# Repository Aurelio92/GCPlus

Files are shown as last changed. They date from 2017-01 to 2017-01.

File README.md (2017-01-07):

# GC+ - What is it?
GC+ is a custom board that acts as a Gamecube controller with an upgradable firmware and custom features.
Video reference: https://www.youtube.com/watch?v=MTG2iqWmXx4

# How to make one?
You can order the PCBs from OshPark: https://oshpark.com/shared_projects/pEYojr6X

# Needed parts
A BOM is available in the Hardware folder

# How to flash it
Flash GC+.hex with MPLAB IPE (http://microchip.wikidot.com/ipe:installation) and a PICKIT v3.

# License

MIT License

Copyright (c) 2016 Aurelio Mannara

Permission is hereby granted, free of charge, to any person obtaining a copy
of this software and associated documentation files (the "Software"), to deal
in the Software without restriction, including without limitation the rights
to use, copy, modify, merge, publish, distribute, sublicense, and/or sell
copies of the Software, and to permit persons to whom the Software is
furnished to do so, subject to the following conditions:

The above copyright notice and this permission notice shall be included in all
copies or substantial portions of the Software.

THE SOFTWARE IS PROVIDED "AS IS", WITHOUT WARRANTY OF ANY KIND, EXPRESS OR
IMPLIED, INCLUDING BUT NOT LIMITED TO THE WARRANTIES OF MERCHANTABILITY,
FITNESS FOR A PARTICULAR PURPOSE AND NONINFRINGEMENT. IN NO EVENT SHALL THE
AUTHORS OR COPYRIGHT HOLDERS BE LIABLE FOR ANY CLAIM, DAMAGES OR OTHER
LIABILITY, WHETHER IN AN ACTION OF CONTRACT, TORT OR OTHERWISE, ARISING FROM,
OUT OF OR IN CONNECTION WITH THE SOFTWARE OR THE USE OR OTHER DEALINGS IN THE
SOFTWARE.

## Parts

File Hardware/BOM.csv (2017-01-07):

Part | Value | Package
C1 | 100 nF | 0805
C2 | 100 nF | 0805
D1 | 1N4148 | SOD-323
IC1 | PIC18F25K22-I/SS | SSOP28
R1 | 10 kohm | 0805
R2 | 10 kohm | 0805
R3 | 10 kohm | 0805
R4 | 10 kohm | 0805
R5 | 10 kohm | 0805
R6 | 10 kohm | 0805
R7 | 10 kohm | 0805
R8 | 10 kohm | 0805
R9 | 10 kohm | 0805
R10 | 100 ohm | 0805
R11 | 10 kohm | 0805
R12 | 10 kohm | 0805
R13 | 10 kohm | 0805
R14 | 10 kohm | 0805
R15 | 10 kohm | 0805
R16 | 10 kohm | 0805
T1 | BSS138_F085 | SOT-23-3

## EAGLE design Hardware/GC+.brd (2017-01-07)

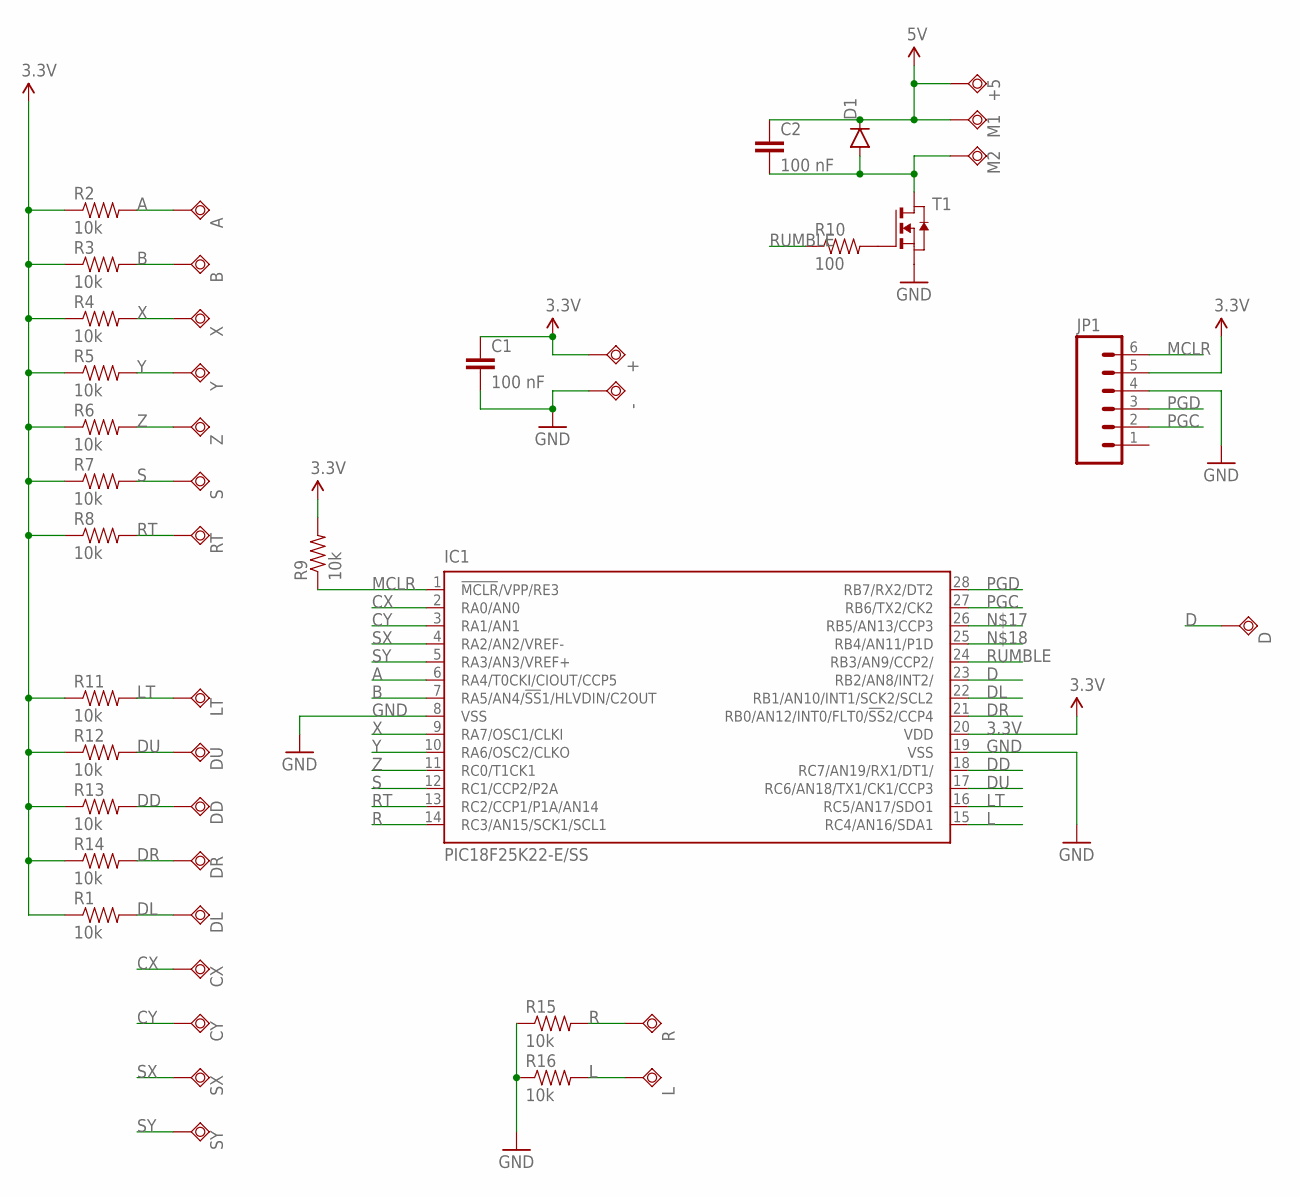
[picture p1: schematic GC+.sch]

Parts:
+, +5: TPSQTP10SQ; TP10SQ
-: TPSQTP10SQ; TP10SQ
A: TPSQTP10SQ; TP10SQ
B: TPSQTP10SQ; TP10SQ
C1, C2: 100 nF; 0805
CX: TPSQTP10SQ; TP10SQ
CY: TPSQTP10SQ; TP10SQ
D: TPSQTP10SQ; TP10SQ
D1: DIODEBAS16; SOD-323
DD: TPSQTP10SQ; TP10SQ
DL: TPSQTP10SQ; TP10SQ
DR: TPSQTP10SQ; TP10SQ
DU: TPSQTP10SQ; TP10SQ
IC1: PIC18F25K22-E/SS; SSOP28
JP1: M06SILK_FEMALE_PTH; 1X06
L: TPSQTP10SQ; TP10SQ
LT: TPSQTP10SQ; TP10SQ
M1, M2: TPSQTP10SQ; TP10SQ
R: TPSQTP10SQ; TP10SQ
R1, R2, R3, R4, R5, R6, R7, R8, R9, R11, R12, R13, R14, R15, R16: 10k; 0805
R10: 100; 0805
RT: TPSQTP10SQ; TP10SQ
S: TPSQTP10SQ; TP10SQ
SX: TPSQTP10SQ; TP10SQ
SY: TPSQTP10SQ; TP10SQ
T1: NMOSSOT23; SOT-23
X: TPSQTP10SQ; TP10SQ
Y: TPSQTP10SQ; TP10SQ
Z: TPSQTP10SQ; TP10SQ

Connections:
3.3V: +.TP, C1.1, IC1.20 (VDD), JP1.5, R1.1, R2.1, R3.1, R4.1, R5.1, R6.1, R7.1, R8.1, R9.2, R11.1, R12.1, R13.1, R14.1
5V: +5.TP, C2.1, D1.C, M1.TP
A: A.TP, IC1.6 (RA4/T0CKI/CIOUT/CCP5), R2.2
B: B.TP, IC1.7 (RA5/AN4/!SS!1/HLVDIN/C2OUT), R3.2
CX: CX.TP, IC1.2 (RA0/AN0)
CY: CY.TP, IC1.3 (RA1/AN1)
D: D.TP, IC1.23 (RB2/AN8/INT2/)
DD: DD.TP, IC1.18 (RC7/AN19/RX1/DT1/), R13.2
DL: DL.TP, IC1.22 (RB1/AN10/INT1/SCK2/SCL2), R1.2
DR: DR.TP, IC1.21 (RB0/AN12/INT0/FLT0/!SS!2/CCP4), R14.2
DU: DU.TP, IC1.17 (RC6/AN18/TX1/CK1/CCP3), R12.2
GND: -.TP, C1.2, IC1.8 (VSS), IC1.19 (VSS), JP1.4, R15.1, R16.1, T1.2 (S)
L: IC1.15 (RC4/AN16/SDA1), L.TP, R16.2
LT: IC1.16 (RC5/AN17/SDO1), LT.TP, R11.2
MCLR: IC1.1 (!MCLR!/VPP/RE3), JP1.6, R9.1
unnamed: R10.2, T1.3 (G)
unnamed: C2.2, D1.A, M2.TP, T1.1 (D)
PGC: IC1.27 (RB6/TX2/CK2), JP1.2
PGD: IC1.28 (RB7/RX2/DT2), JP1.3
R: IC1.14 (RC3/AN15/SCK1/SCL1), R.TP, R15.2
RT: IC1.13 (RC2/CCP1/P1A/AN14), R8.2, RT.TP
RUMBLE: IC1.24 (RB3/AN9/CCP2/), R10.1
S: IC1.12 (RC1/CCP2/P2A), R7.2, S.TP
SX: IC1.4 (RA2/AN2/VREF-), SX.TP
SY: IC1.5 (RA3/AN3/VREF+), SY.TP
X: IC1.9 (RA7/OSC1/CLKI), R4.2, X.TP
Y: IC1.10 (RA6/OSC2/CLKO), R5.2, Y.TP
Z: IC1.11 (RC0/T1CK1), R6.2, Z.TP

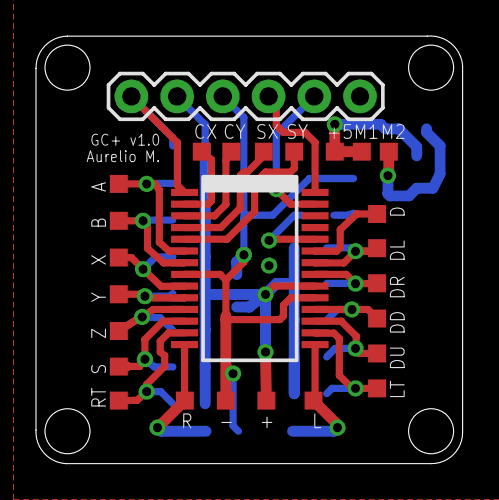
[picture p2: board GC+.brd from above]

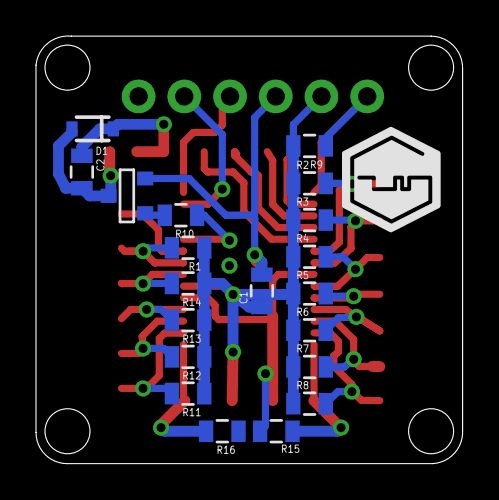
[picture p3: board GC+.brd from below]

Board: 2 copper layers, 23.7 x 23.8 mm, 47 parts (20 on the bottom side), 28 nets.

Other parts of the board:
U$1: LOGOGC

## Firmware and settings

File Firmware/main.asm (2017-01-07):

; GC+ by Aurelio Mannara


; MIT License
; 
; Copyright (c) 2016 Aurelio Mannara
; 
; Permission is hereby granted, free of charge, to any person obtaining a copy
; of this software and associated documentation files (the "Software"), to deal
; in the Software without restriction, including without limitation the rights
; to use, copy, modify, merge, publish, distribute, sublicense, and/or sell
; copies of the Software, and to permit persons to whom the Software is
; furnished to do so, subject to the following conditions:
; 
; The above copyright notice and this permission notice shall be included in all
; copies or substantial portions of the Software.
; 
; THE SOFTWARE IS PROVIDED "AS IS", WITHOUT WARRANTY OF ANY KIND, EXPRESS OR
; IMPLIED, INCLUDING BUT NOT LIMITED TO THE WARRANTIES OF MERCHANTABILITY,
; FITNESS FOR A PARTICULAR PURPOSE AND NONINFRINGEMENT. IN NO EVENT SHALL THE
; AUTHORS OR COPYRIGHT HOLDERS BE LIABLE FOR ANY CLAIM, DAMAGES OR OTHER
; LIABILITY, WHETHER IN AN ACTION OF CONTRACT, TORT OR OTHERWISE, ARISING FROM,
; OUT OF OR IN CONNECTION WITH THE SOFTWARE OR THE USE OR OTHER DEALINGS IN THE
; SOFTWARE.

#include "p18F25K22.inc"

; CONFIG1H
  CONFIG  FOSC = INTIO67        ; Oscillator Selection bits (Internal oscillator block)
  CONFIG  PLLCFG = ON           ; 4X PLL Enable (Oscillator multiplied by 4)
  CONFIG  PRICLKEN = OFF        ; Primary clock enable bit (Primary clock can be disabled by software)
  CONFIG  FCMEN = OFF           ; Fail-Safe Clock Monitor Enable bit (Fail-Safe Clock Monitor disabled)
  CONFIG  IESO = OFF            ; Internal/External Oscillator Switchover bit (Oscillator Switchover mode disabled)

; CONFIG2L
  CONFIG  PWRTEN = OFF          ; Power-up Timer Enable bit (Power up timer disabled)
  CONFIG  BOREN = SBORDIS       ; Brown-out Reset Enable bits (Brown-out Reset enabled in hardware only (SBOREN is disabled))
  CONFIG  BORV = 190            ; Brown Out Reset Voltage bits (VBOR set to 1.90 V nominal)

; CONFIG2H
  CONFIG  WDTEN = SWON          ; Watchdog Timer Enable bits (WDT is controlled by SWDTEN bit of the WDTCON register)
  CONFIG  WDTPS = 1024          ; Watchdog Timer Postscale Select bits (1:1024)

; CONFIG3H
  CONFIG  CCP2MX = PORTB3       ; CCP2 MUX bit (CCP2 input/output is multiplexed with RB3)
  CONFIG  PBADEN = ON           ; PORTB A/D Enable bit (PORTB<5:0> pins are configured as analog input channels on Reset)
  CONFIG  CCP3MX = PORTB5       ; P3A/CCP3 Mux bit (P3A/CCP3 input/output is multiplexed with RB5)
  CONFIG  HFOFST = ON           ; HFINTOSC Fast Start-up (HFINTOSC output and ready status are not delayed by the oscillator stable status)
  CONFIG  T3CMX = PORTC0        ; Timer3 Clock input mux bit (T3CKI is on RC0)
  CONFIG  P2BMX = PORTB5        ; ECCP2 B output mux bit (P2B is on RB5)
  CONFIG  MCLRE = EXTMCLR       ; MCLR Pin Enable bit (MCLR pin enabled, RE3 input pin disabled)

; CONFIG4L
  CONFIG  STVREN = ON           ; Stack Full/Underflow Reset Enable bit (Stack full/underflow will cause Reset)
  CONFIG  LVP = ON              ; Single-Supply ICSP Enable bit (Single-Supply ICSP enabled if MCLRE is also 1)
  CONFIG  XINST = OFF           ; Extended Instruction Set Enable bit (Instruction set extension and Indexed Addressing mode disabled (Legacy mode))

; CONFIG5L
  CONFIG  CP0 = ON             ; Code Protection Block 0 (Block 0 (000800-001FFFh) code-protected)
  CONFIG  CP1 = ON             ; Code Protection Block 1 (Block 1 (002000-003FFFh) code-protected)
  CONFIG  CP2 = ON             ; Code Protection Block 2 (Block 2 (004000-005FFFh) code-protected)
  CONFIG  CP3 = ON             ; Code Protection Block 3 (Block 3 (006000-007FFFh) code-protected)

; CONFIG5H
  CONFIG  CPB = ON             ; Boot Block Code Protection bit (Boot block (000000-0007FFh) code-protected)
  CONFIG  CPD = OFF            ; Data EEPROM Code Protection bit (Data EEPROM not code-protected)

; CONFIG6L
  CONFIG  WRT0 = ON             ; Write Protection Block 0 (Block 0 (000800-001FFFh) write-protected)
  CONFIG  WRT1 = OFF            ; Write Protection Block 1 (Block 1 (002000-003FFFh) not write-protected)
  CONFIG  WRT2 = OFF            ; Write Protection Block 2 (Block 2 (004000-005FFFh) not write-protected)
  CONFIG  WRT3 = OFF            ; Write Protection Block 3 (Block 3 (006000-007FFFh) not write-protected)

; CONFIG6H
  CONFIG  WRTC = ON             ; Configuration Register Write Protection bit (Configuration registers (300000-3000FFh) write-protected)
  CONFIG  WRTB = ON             ; Boot Block Write Protection bit (Boot Block (000000-0007FFh) write-protected)
  CONFIG  WRTD = OFF            ; Data EEPROM Write Protection bit (Data EEPROM not write-protected)

; CONFIG7L
  CONFIG  EBTR0 = ON            ; Table Read Protection Block 0 (Block 0 (000800-001FFFh) protected from table reads executed in other blocks)
  CONFIG  EBTR1 = ON            ; Table Read Protection Block 1 (Block 1 (002000-003FFFh) protected from table reads executed in other blocks)
  CONFIG  EBTR2 = ON            ; Table Read Protection Block 2 (Block 2 (004000-005FFFh) protected from table reads executed in other blocks)
  CONFIG  EBTR3 = ON            ; Table Read Protection Block 3 (Block 3 (006000-007FFFh) protected from table reads executed in other blocks)

; CONFIG7H
  CONFIG  EBTRB = ON            ; Boot Block Table Read Protection bit (Boot Block (000000-0007FFh) protected from table reads executed in other blocks)

;Some global variables
bitCounter equ 0x00
tempCmdByte equ 0x01
cmdReceived equ 0x02
cmdLength equ 0x03
charToSendUart1 equ 0x04
dataLength equ 0x05
bitCounterTX equ 0x06
curByte equ 0x07
waitLoopCounter equ 0x08
curADInput equ 0x09
f_divhi equ 0x0A
f_divlo equ 0x0B
lutCounter equ 0x0C
invertAxes equ 0x0D
deadZoneSize equ 0x0E
rumbleDutyCycle equ 0x0F
 
;0x10-0x1F received commands
;0x20-0x22 0x00 answer
;0x23-0x24 buttons current state
buttonsCurState0 equ 0x23
buttonsCurState1 equ 0x24
;0x25-0x26 buttons prev state
buttonsPrevState0 equ 0x25
buttonsPrevState1 equ 0x26
;0x27-0x2C buttons timers
buttonsTimerA equ 0x27
buttonsTimerB equ 0x28
buttonsTimerX equ 0x29
buttonsTimerY equ 0x2A
buttonsTimerZ equ 0x2B
buttonsTimerS equ 0x2C
;0x2D-0x2E mixed buttons state
buttonsMixState0 equ 0x2D
buttonsMixState1 equ 0x2E
;0x30-0x37 0x40 answer
;0x38-0x3D buttons timers
buttonsTimerRT equ 0x38
buttonsTimerLT equ 0x39
buttonsTimerDU equ 0x3A
buttonsTimerDD equ 0x3B
buttonsTimerDR equ 0x3C
buttonsTimerDL equ 0x3D
;0x3E flagsSettings
flagsSettings equ 0x3E
;0x3F analog mode
analogMode equ 0x3F
;0x40-0x4F 0x41-0x42 answer
;0x50-0x55 AD inputs
;0x56-0x5B AD origins

;0x100-0x1FF SX LUT
;0x200-0x2FF SY LUT
;0x300-0x3FF CX LUT
;0x400-0x4FF CY LUT

;Global constant values
firmMajVer equ 1
firmMinVer equ 1
boardMajVer equ 1
boardMinVer equ 0
 
    ;EEPROM default values
    org 0xF00000
    de 0xFF, 0x00, 0xFF, 0x00, 0xFF, 0x00, 0xFF, 0x00, 0x00, 0x18, 0x00


    org 0x00
    goto start
    
    org 0x08 ;High-priority interrupts
    goto isrHighHandler
    
    org 0x18 ;Low-priority interrupts
    goto isrLowHandler

    org 0x20
isrHighHandler
    btfss INTCON3, 1 ;If INT2 flag isn't set just return
    retfie 1 ;Return from interrupt and restore W, STATUS and BSR registers
    ;If we got here, then INT2 flag is set
    
    movlw 0x80 ;Starts from 128 => Wait only 8us
    movwf TMR0L
    bcf INTCON, 2 ;Clear TMR0 flag
    
    ;Check cmdLength
    movf cmdLength, 0, 0 ;WREG = cmdLength
    addlw 0xF1 ;241 = 255 - 14
    addlw 0x0F ;(14 - 0) + 1
    bnc endIsrHighHandler

    ;movlw 0x0E
    ;subfwb cmdLength, 1, 0 ;W = 14 - cmdLength
    ;btfss STATUS, 0 ;Test if cmdLength > 14
    ;bra endIsrHighHandler
    
    ;Wait few cycles => Wait for ~1.25us since the falling edge
    nop
    nop
    nop
    nop
    nop
    nop
    nop
    nop
    nop
    
    ;Check if bitCounter is 8
    movf bitCounter, 0, 0 ;Move bitCounter to W. Use Access Bank
    sublw 8 ;WREG = WREG - 8
    bnz readIsrBit
    
    ;If we got here then we have received a byte
    clrf bitCounter, 0 ;Use Access Bank
    movff tempCmdByte, POSTINC0
    clrf tempCmdByte, 0 ;Use Access Bank
    incf cmdLength, 1, 0 ;Use Access Bank
    
readIsrBit
    
    ;Read the data from RB2 and store it in the tempCmdByte
    rlncf tempCmdByte, 1, 0 ;Use Access Bank
    btfsc PORTB, 2 ;Test RB2. Skip if clear
    bsf tempCmdByte, 0, 0 ;Set the LSB of tempCmdByte if RB2 is set
    incf bitCounter, 1, 0 ;Use Access Bank
    
    
endIsrHighHandler
    bcf INTCON3, 1 ;Clear INT2 flag
    retfie 1 ;Return from interrupt and restore W, STATUS and BSR registers
    
isrLowHandler
    btfsc INTCON, 2 ;Test if the TMR0 overflow occurred
    bra isrTMR0Handler
    
    ;btfsc PIR1, 6 ;Test if AD conversion has happened
    ;bra isrADCHandler
    
    retfie 1 ;Return from interrupt and restore W, STATUS and BSR registers

isrTMR0Handler
    tstfsz cmdLength, 0 ;Skip if cmdLength == 0
    bra isrTMR0CmdReceived
    bra isrTMR0SkipCmdReceived
isrTMR0CmdReceived
    bsf cmdReceived, 0, 0 ;Use Access Bank
    
isrTMR0SkipCmdReceived
    movlw 0x80 ;Starts from 128 => Wait only 8us
    movwf TMR0L
    bcf INTCON, 2 ;Clear TMR0 flag
    retfie 1 ;Return from interrupt and restore W, STATUS and BSR registers
    
    org 0x100
start
    movlb 0xF ; Set BSR for banked SFRs
    bcf INTCON, 7 ;Disable global high interrupts
    bcf WDTCON, 0 ;Make sure that the WDT is disabled
    
    ;Configure oscillator
    movlw 0x74
    movwf OSCCON
    movlw 0x00
    movwf OSCCON2
    movlw 0x40
    movwf OSCTUNE
    ;bsf OSCTUNE, 6 ;OSCTUNE.PLLEN = 1
    
    
    ;Clear the first chunk of memory
    movlw 0x5b
    lfsr FSR0, 0x000
    clrf INDF0
clearMemoryLoop
    movwf FSR0L
    clrf INDF0
    decf WREG
    bnz clearMemoryLoop
    
    
    ;clrf LATB
    ;movlw 0x00
    ;movwf ANSELB
    ;bsf TRISB, 2
    ;bcf LATB, 2
    
    ;Clear global variables to be safe
    clrf tempCmdByte, 0 ;Use Access Bank
    clrf bitCounter, 0 ;Use Access Bank
    clrf cmdReceived, 0 ;Use Access Bank
    clrf cmdLength, 0 ;Use Access Bank
    
    lfsr FSR0, 0x10 ;FSR0 at the beginning of Bank 1
    
    ;CMD 0x00 answer
    lfsr FSR1, 0x20 ;FSR1 at 0x20
    movlw 0x09
    movwf POSTINC1
    movlw 0x00
    movwf POSTINC1
    movlw 0x03
    movwf POSTINC1
    
    ;CMD 0x41-0x42 answer
    lfsr FSR1, 0x40 ;FSR1 at 0x40
    movlw 0x00
    movwf POSTINC1
    movlw 0x80
    movwf POSTINC1
    movlw 0x80
    movwf POSTINC1
    movlw 0x80
    movwf POSTINC1
    movlw 0x80
    movwf POSTINC1
    movlw 0x80
    movwf POSTINC1
    movlw 0x00
    movwf POSTINC1
    movlw 0x00
    movwf POSTINC1
    movlw 0x00
    movwf POSTINC1
    movlw 0x00
    movwf POSTINC1
    
    ;Configuring analog inputs
    movlw 0x0F
    movwf ANSELA
    movlw 0x00
    movwf ANSELB
    movlw 0x18
    movwf ANSELC
    
    ;Setting inputs
    movlw 0xFF
    movwf TRISA
    movlw 0x07
    movwf TRISB
    movlw 0xFF
    movwf TRISC
    
    ;Set ADC
    movlw 0x09
    movwf ADCON0
    movlw 0x00
    movwf ADCON1
    movlw 0x3E
    ;movlw 0x08
    movwf ADCON2
    
    bcf PIR1, 6 ;ADIF = 0
    bcf PIE1, 6 ;ADIE = 0
    bcf IPR1, 6 ;ADIP low priority
    
    call buildOrigins

    ;Check if the board is booted in safe mode
    ;Hold X+Y+Z for safe mode
    bsf flagsSettings, 0, 0 ;Enable safe mode
    btfsc PORTA, 7 ;Skip if X is pressed
    bcf flagsSettings, 0, 0 ;Disable safe mode
    btfsc PORTA, 6 ;Skip if Y is pressed
    bcf flagsSettings, 0, 0 ;Disable safe mode
    btfsc PORTC, 0 ;Skip if Z is pressed
    bcf flagsSettings, 0, 0 ;Disable safe mode
    
    ;If X+Y+A are pressed on boot then reset the ranges to default
    btfsc PORTA, 6
    bra lutStart
    btfsc PORTA, 7
    bra lutStart
    btfsc PORTA, 4 ;A
    bra lutStart
    
    
    ;SXmax
    movlw 0x00
    movwf EEADR
    movlw 0xFF
    movwf EEDATA
    call EEPROMWrite
    
    
    ;SXmin
    movlw 0x01
    movwf EEADR
    movlw 0x00
    movwf EEDATA
    call EEPROMWrite
    
    ;SYmax
    movlw 0x02
    movwf EEADR
    movlw 0xFF
    movwf EEDATA
    call EEPROMWrite
    
    ;SYmin
    movlw 0x03
    movwf EEADR
    movlw 0x00
    movwf EEDATA
    call EEPROMWrite
    
    ;CXmax
    movlw 0x04
    movwf EEADR
    movlw 0xFF
    movwf EEDATA
    call EEPROMWrite
    
    ;CXmin
    movlw 0x05
    movwf EEADR
    movlw 0x00
    movwf EEDATA
    call EEPROMWrite
    
    ;CYmax
    movlw 0x06
    movwf EEADR
    movlw 0xFF
    movwf EEDATA
    call EEPROMWrite
    
    ;CYmin
    movlw 0x07
    movwf EEADR
    movlw 0x00
    movwf EEDATA
    call EEPROMWrite
    
    ;Invert axes
    movlw 0x08
    movwf EEADR
    movlw 0x00
    movwf EEDATA
    call EEPROMWrite
    
    ;Dead Zone Size
    movlw 0x09
    movwf EEADR
    movlw 0x18
    movwf EEDATA
    call EEPROMWrite
    
    ;Rumble Duty Cycle
    movlw 0x0A
    movwf EEADR
    movlw 0x00
    movwf EEDATA
    call EEPROMWrite

    ;Call customEEPROMSettings if not in safe mode
    btfss flagsSettings, 0, 0
    call customEEPROMSettings
    
    
lutStart
    ;EEDATA will hold range min
    ;tempCmdByte used as temp var for range
    
    movlw 0x09 ;Dead Zone Size
    movwf EEADR
    call EEPROMRead
    movff EEDATA, deadZoneSize
    
    movlw 0x0A ;Rumble Duty Cycle
    movwf EEADR
    call EEPROMRead
    movff EEDATA, rumbleDutyCycle
    
    movlw 0x08 ;Invert SX?
    movwf EEADR
    call EEPROMRead
    movlw 0x00
    movwf invertAxes, 0 ;Use Access Bank
    btfsc EEDATA, 0 ;SX invertAxis bit
    bsf invertAxes, 0, 0
    
    
    movlw 0x00
    movwf EEADR
    lfsr FSR2, 0x100 ;SX
    call lutBuild
    
    movlw 0x08 ;Invert SY?
    movwf EEADR
    call EEPROMRead
    movlw 0x00
    movwf invertAxes, 0 ;Use Access Bank
    btfsc EEDATA, 1 ;SY invertAxis bit
    bsf invertAxes, 0, 0
    
    movlw 0x02
    movwf EEADR
    lfsr FSR2, 0x200 ;SY
    call lutBuild
    
    movlw 0x08 ;Invert CX?
    movwf EEADR
    call EEPROMRead
    movlw 0x00
    movwf invertAxes, 0 ;Use Access Bank
    btfsc EEDATA, 2 ;CX invertAxis bit
    bsf invertAxes, 0, 0
    
    movlw 0x04
    movwf EEADR
    lfsr FSR2, 0x300 ;CX
    call lutBuild
    
    movlw 0x08 ;Invert CY?
    movwf EEADR
    call EEPROMRead
    movlw 0x00
    movwf invertAxes, 0 ;Use Access Bank
    btfsc EEDATA, 3 ;CY invertAxis bit
    bsf invertAxes, 0, 0
    
    movlw 0x06
    movwf EEADR
    lfsr FSR2, 0x400 ;CY
    call lutBuild
    
    
    ;Setup PWM for rumble
    bsf TRISB, 3 ;Disable rumble output (CCP2)
    bcf CCPTMRS0, 3 ;Use Timer2 for CCP2
    bcf CCPTMRS0, 4
    ;3.90 kHz
    movlw 0xFF
    movwf PR2
    movlw 0x0F ;PWM mode
    movwf CCP2CON
    setf CCPR2L ;Disable rumble
    bcf PIR2, 1
    movlw 0x07 ;1:16 prescaler
    movwf T2CON
    bcf TRISB, 3 ;Enable rumble output
    
    
    ;Setup Timer 4 for debouncing (1ms timer)
    movlw 0x40
    movwf PR4
    bcf PIE5, 0 ;Timer 4 interrupt disable
    bcf PIR5, 0 ;Clear TMR4IF
    movlw 0x7F
    movwf T4CON
    
    ;Default values for buttons
    ;The GC expect active high buttons
    clrf buttonsCurState0, 0 ;Access bank
    clrf buttonsCurState1, 0 ;Access bank
    clrf buttonsPrevState0, 0 ;Access bank
    clrf buttonsPrevState1, 0 ;Access bank
    ;Default values for buttons timers
    clrf buttonsTimerA, 0 ;Access bank
    clrf buttonsTimerB, 0 ;Access bank
    clrf buttonsTimerX, 0 ;Access bank
    clrf buttonsTimerY, 0 ;Access bank
    clrf buttonsTimerZ, 0 ;Access bank
    clrf buttonsTimerS, 0 ;Access bank
    clrf buttonsTimerRT, 0 ;Access bank
    clrf buttonsTimerLT, 0 ;Access bank
    clrf buttonsTimerDU, 0 ;Access bank
    clrf buttonsTimerDD, 0 ;Access bank
    clrf buttonsTimerDR, 0 ;Access bank
    clrf buttonsTimerDL, 0 ;Access bank

    ;Enable pull-up on data line
    bsf WPUB, 2
    bcf INTCON2, 7

    ;Call customInit if not in safe mode
    btfss flagsSettings, 0, 0
    call customInit
    
    ;Configure INT2 interrupt
    bcf INTCON3, 1 ;Clear INT2 flag
    bcf INTCON2, 4 ;INT2 on falling edge
    bsf INTCON3, 4 ;Enable INT2
    bsf INTCON3, 7 ;INT2 high priority
    
    bsf RCON, 7 ;Enable priority levels on interrupts
    
    movlw 0x48 ;TMR0 disabled. 8bit. 1:1 (16us). Fosc/4
    movwf T0CON
    movlw 0x80 ;Starts from 128 => Wait only 8us
    movwf TMR0L
    movlw 0x00
    movwf TMR0H ;Not used, but meh
    bcf INTCON, 2 ;TMR0IF = 0
    bsf INTCON, 5 ;TMR0IE = 1
    bcf INTCON2, 2 ;TMR0 low priority
    
    bsf T0CON, 7 ;Enable TMR0
    bsf INTCON, 6 ;Enable global low interrupts
    bsf INTCON, 7 ;Enable global high interrupts
    
    bsf ADCON0, 1
    
    bsf WDTCON, 0 ;Enable WDT

    btfss flagsSettings, 0, 0
    goto customLoopCode
    
mainLoop
    ;Clear WDT only if X, Y and Start are not pressed together
    ; => Clear WDT if at least one of the X, Y, Start is not pressed
    
    btfsc PORTA, 7 ;X
    clrwdt
    btfsc PORTA, 6 ;Y
    clrwdt
    btfsc PORTC, 1 ;Start
    clrwdt

    btfsc cmdReceived, 0, 0
    call handleCmd

    call readButtonsAndDebounce
    
    btfss ADCON0, 1 ;Check if the ADC is done
    call getADC
    
    goto mainLoop
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

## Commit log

2017-01-07 First public release
    [BOM.csv, GC+.brd, GC+.sch]
2017-01-07 Fixed the BOM
    [BOM.csv]

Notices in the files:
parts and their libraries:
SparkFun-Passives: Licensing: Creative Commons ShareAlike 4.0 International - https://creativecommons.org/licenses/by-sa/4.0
